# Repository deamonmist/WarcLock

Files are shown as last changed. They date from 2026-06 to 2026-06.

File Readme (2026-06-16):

# WarcLock

> **A wardriving pocket watch with style.**

**By Deamonmist**

A portable war-driver built from basic components that passes as a nifty home-made analog clock. It shows the real time on a round TFT face with a satellite-connection indicator, battery gauge, active-wardriving indicator, and random messages — all wrapped in a digital Art Deco style.

---
## Contents

- Mission Statement
- Overall Design
  - Form Factor
  - Components
- Assembly
  - Wiring Diagrams
    - ATGM336H — GPS Module
    - GC9A01 — Round TFT Display
    - V474 — SD Card Module
    - XIAO ESP32-C5 — MCU Pin Usage
    - On/Off Switch (Left Side)
    - Wardrive Slide Switch (Right Side)
    - Dim Tactile Button
    - LiPo Battery
    - Battery Voltage Sense Circuit
  - Circuit Assembly
- 3D Printing
- Final Assembly
- Flashing Your XIAO ESP32-C5

---
## Mission Statement

The goal of this project is simple: use basic components to make a portable war-driver that can pass as some kind of nifty home-made clock.

---
## Overall Design

### Form Factor
A small 3D-printed case containing a series of small modules and development boards that display the real time on an analog clock. The clock comes with a satellite-connection indicator, battery-life gauge, active-wardriving indicator, and random messages. The design is based on a digital Art Deco style.

### Components
- **GPS module** (ATGM336H) with ceramic antenna
- **1.28" round TFT screen** (GC9A01)
- **SD module**
- **XIAO ESP32-C5**
- **400mAh LiPo battery** (AKZYTUE 3.7V 522332)
- **Perforated board**
- Leads
- Two sliding switches
- One tactile switch

---

## Assembly

### Wiring Diagrams
Complete pin mapping for all components.

**Note:** The XIAO ESP32-C5 silkscreen D-numbers do **not** match the GPIO numbers. Always use the **GPIO** column when writing firmware.

#### ATGM336H — GPS Module
| GPS Pin | XIAO Pin | GPIO |
| --- | --- | --- |
| TX | D7 (RX) | GPIO12 |
| RX | D6 (TX) | GPIO11 |
| VCC | 3V3 | — |
| GND | GND | — |

#### GC9A01 — Round TFT Display
| TFT Pin | XIAO Pin | GPIO |
| --- | --- | --- |
| SCL / SCK | D8 | GPIO8 |
| SDA / MOSI | D10 | GPIO10 |
| CS | D2 | GPIO25 |
| DC | D3 | GPIO7 |
| RST | D1 | GPIO0 |
| VCC | 3V3 | — |
| GND | GND | — |

#### V474 — SD Card Module
| SD Pin | XIAO Pin | GPIO |
| --- | --- | --- |
| SCK | D8 (shared SPI) | GPIO8 |
| MOSI | D10 (shared SPI) | GPIO10 |
| MISO | D9 (shared SPI) | GPIO9 |
| CS | D0 | GPIO1 |
| VCC | 3V3 | — |
| GND | GND | — |

#### XIAO ESP32-C5 — MCU Pin Usage
| Function | XIAO Pin | GPIO |
| --- | --- | --- |
| SPI SCK | D8 | GPIO8 |
| SPI MOSI | D10 | GPIO10 |
| SPI MISO | D9 | GPIO9 |
| GPS RX (← GPS TX) | D7 | GPIO12 |
| GPS TX (→ GPS RX) | D6 | GPIO11 |
| TFT CS | D2 | GPIO25 |
| TFT DC | D3 | GPIO7 |
| TFT RST | D1 | GPIO0 |
| SD CS | D0 | GPIO1 |
| Wardrive Switch | D5 | GPIO24 |
| Dim Button | D4 | GPIO23 |
| Battery +/− | BAT pads | — |

#### On/Off Switch (Left Side)
| Switch Leg | XIAO Pin | GPIO |
| --- | --- | --- |
| Leg 1 (signal) | Bat + on XIAO| — |
| Leg 2 (common) | Bat + on Battery | — |
Interrupt the positive battery line with a switch.

#### Wardrive Slide Switch (Right Side)
| Switch Leg | XIAO Pin | GPIO |
| --- | --- | --- |
| Leg 1 (signal) | D5 | GPIO24 |
| Leg 2 (common) | GND | — |
`LOW` = wardrive active. `HIGH` = idle. Internal pullup enabled in firmware.

#### Dim Tactile Button
| Button Leg | XIAO Pin | GPIO |
| --- | --- | --- |
| Leg 1 (signal) | D4 | GPIO23 |
| Leg 2 (common) | GND | — |
Press toggles black-screen dim. Auto-dims after 2 minutes. Internal pullup enabled.

#### LiPo Battery
| Battery Wire | XIAO Pad | Note |
| --- | --- | --- |
| Positive (+) | BAT + | Soldered direct to pad |
| Negative (−) | BAT − | Soldered direct to pad |
Charged via USB-C. The onboard SGM40567 handles charge management. Do not exceed the 500mAh cell rating.

#### Battery Voltage Sense Circuit (onboard)
| Signal | XIAO Pin | GPIO | Note |
| --- | --- | --- | --- |
| ADC input | — | GPIO6 | Reads divided BAT voltage |
| ADC enable | Back pad A4 | GPIO26 | Drive HIGH to enable, LOW when idle |

---
### Circuit Assembly

Because a perforated board, modules, and dev boards are being packed into a very small space, there is a lot to fit. A general step-by-step visual guide is provided, but representing the wiring visually is too challenging — please refer to the [wiring diagrams](#wiring-diagrams) above.

Download READ-Me-WarcLock.docx for step by step instructions with pictures.

## 3D Printing
There are **5 parts** to print, listed on the GitHub page for download. From bottom to top:

- `ClockBottomInlay.stl`
- `ClockBottomSupports.stl`
- `ClockBodywSupports.stl`
- `ClockTopwSuppports.stl`
- `ClockDetailInlay.stl`

All prints include designed-in supports. If they're laid flat for printing, you should not need to add any slicer supports.

> 🛠️ You may occasionally get an error on `ClockBodywSupports.stl`. You can enable slicer supports, but they make it harder to remove the design supports. If this file starts to spaghettify, enable supports.

---
## Final Assembly

Refer to READ-Me-WarcLock.docx for step by step instructions with pictures.

The pieces used in final construction, from left to right:

- `ClockBottomInlay.stl`
- `ClockBottomwSupports.stl`
- WiFi antenna
- `ClockBodywSupports.stl`
- Soldered components
- `ClockTopwSupports.stl`
- `ClockDetailInlay.stl`

1. Apply super glue to the back of the bottom plate.
2. Attach the back plate to the bottom plate (and place an NFC tag if desired).
3. The antenna that comes with the XIAO ESP32-C5 must have its connection end fed through the hole in the clock body housing.
4. The connection end of the antenna fits easily.
5. Attach the antenna connection end to the XIAO ESP32-C5's U.FL port.
6. Carefully place the clock into the clock body housing. You'll have to bend the wings of the slide switches to fit the slots made for them.
7. Test your hardware to ensure none of the cabling was compromised during the fitting.
8. Place the ceramic antenna into the slot at the bottom of the clock body housing.
9. Attach the antenna to the back of the clock body housing.
10. Remove the two sticker backs from the antenna and stick it in place.
11. Attach the assembled backplate to the bottom of the clock body housing. This may be glued later.
12. Carefully glue the tactile push button into the slot at the front of the clock top housing. The slit allows the button's wires to be buried into the clock body housing.
13. Begin to fit the clock top housing onto the clock body housing.
14. Once everything is working and fits snugly, use a few small dabs of super glue to make the assembly more permanent.

---
## Flashing Your XIAO ESP32-C5
The firmware that drives the clock display and wardriving was written for this project. Consider flashing it onto your XIAO ESP32-C5 **before** you stuff everything into the 3D-printed parts.

Use the Arduino IDE to install the firmware. There are **10 files** in total — drop all 10 into a new folder and open `WarcLock.ino` to get started.

You will need the following libraries:

```cpp
#include <Arduino.h>
#include <Arduino_GFX_Library.h>
#include <math.h>
#include <HardwareSerial.h>
#include <WiFi.h>
#include <SPI.h>
#include <SD.h>
```

The rest of the dependencies are included in the project files.

> When in doubt, flash again!

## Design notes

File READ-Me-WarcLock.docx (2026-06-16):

WarcLock

By Deamonmist

A wardriving pocket watch with style.

Readme

June 15th, 2026 | Status: 1.0.0-beta.1

# Contents

Pg 1. – Contents

Pg 1. – Mission Statement

Pg 2. – Overall Design

– Form Factor

– Components

Pg 3. – Assembly

– Wiring Diagrams

Pg 5. – Circuit Assembly

Pg 9. – 3D Printing

Pg 10. – Final Assembly
Pg 18. – Flashing Your XIAO ESP32-C5

# Mission Statement

The goal of this project is simple: use basic components to make a portable war-driver that can pass as some kind of nifty home-made clock.

# Overall Design

## Form Factor

Small 3d-printed case containing a series of small modules and development boards that can display the real time on an analog clock. Clock comes with satellite connection indicator, battery life gauge, active wardriving indicator, and random messages. The design is based on a digital Arte Deco style.

## Components

- GPS module (ATGM336H) with ceramic antenna
- 1.28” TFT screen (GC9A01TFT)
- SD Module
- Xiao ESP32-C5
- 400mAh LiPo battery (AKZYTUE 3.7V 522332)
- Perforated Board
- Leads
- Two sliding switches
- 1 tactile switch

# Assembly

## Wiring Diagrams

Complete pin mapping for all components. XIAO ESP32-C5 silkscreen D-numbers do not match GPIO numbers — always use the GPIO column when writing firmware.

## ATGM336H — GPS Module

GPS Pin | XIAO Pin | GPIO
TX | D7 (RX) | GPIO12
RX | D6 (TX) | GPIO11
VCC | 3V3 | —
GND | GND | —

## GC9A01 — Round TFT Display

TFT Pin | XIAO Pin | GPIO
SCL / SCK | D8 | GPIO8
SDA / MOSI | D10 | GPIO10
CS | D2 | GPIO25
DC | D3 | GPIO7
RST | D1 | GPIO0
VCC | 3V3 | —
GND | GND | —

## V474 — SD Card Module

SD Pin | XIAO Pin | GPIO
SCK | D8 (shared SPI) | GPIO8
MOSI | D10 (shared SPI) | GPIO10
MISO | D9 (shared SPI) | GPIO9
CS | D0 | GPIO1
VCC | 3V3 | —
GND | GND | —

## XIAO ESP32-C5 — MCU Pin Usage

Function | XIAO Pin | GPIO
SPI SCK | D8 | GPIO8
SPI MOSI | D10 | GPIO10
SPI MISO | D9 | GPIO9
GPS RX (← GPS TX) | D7 | GPIO12
GPS TX (→ GPS RX) | D6 | GPIO11
TFT CS | D2 | GPIO25
TFT DC | D3 | GPIO7
TFT RST | D1 | GPIO0
SD CS | D0 | GPIO1
Wardrive Switch | D5 | GPIO24
Dim Button | D4 | GPIO23
Battery +/− | BAT pads | —

## On Off Switch (Left Side)

Switch Leg | XIAO Pin | GPIO
Leg 1 (signal) | Bat +
Leg 2 (common) | Bat + | —

Interrupt the positive battery line with a switch.

## Wardrive Slide Switch (Right Side)

Switch Leg | XIAO Pin | GPIO
Leg 1 (signal) | D5 | GPIO24
Leg 2 (common) | GND | —

LOW = wardrive active. HIGH = idle. Internal pullup enabled in firmware.

## Dim Tactile Button

Button Leg | XIAO Pin | GPIO
Leg 1 (signal) | D4 | GPIO23
Leg 2 (common) | GND | —

Press toggles black-screen dim. Auto-dims after 2 minutes. Internal pullup enabled.

## LiPo Battery (500mAh)

Battery Wire | XIAO Pad | Note
Positive (+) | BAT + | Soldered direct to pad
Negative (−) | BAT − | Soldered direct to pad

Charged via USB-C. SGM40567 onboard handles charge management. Do not exceed 500mAh cell rating.

## Battery Voltage Sense Circuit (onboard)

Signal | XIAO Pin | GPIO | Note
ADC input | — | GPIO6 | Reads divided BAT voltage
ADC enable | Back pad A4 | GPIO26 | Drive HIGH to enable, LOW when idle

# Circuit Assembly

Because a perforated board, modules, and dev boards are being used there is a lot to pack in a very small space. I have provided a general step by step visual guide. However, visually representing wiring is too challenging. Please refer to the wiring diagrams above.

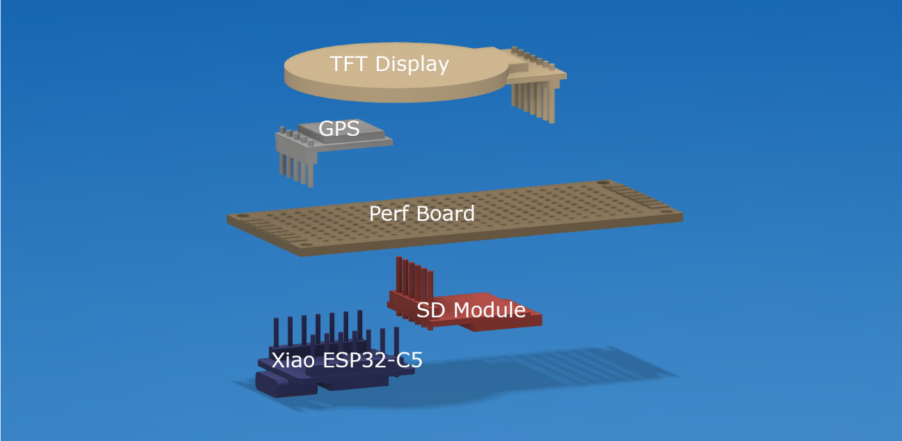
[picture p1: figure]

This is the rough orientation of the various components.

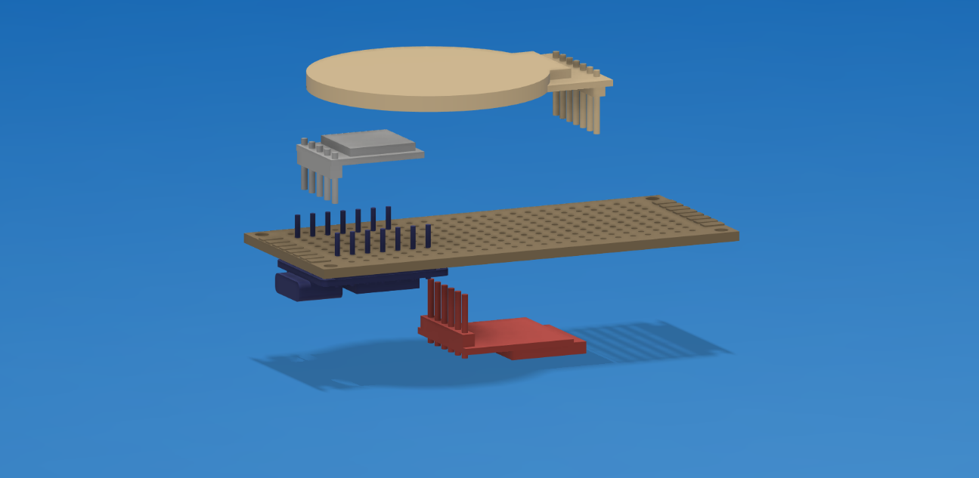
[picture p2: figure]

Start by moving the Xiao ESP32-C5 into the location shown. Solder one or two of the posts to the breadboard to keep it in place. Alternatively you can bend a pin or two flush with perf-board to hold it in place.

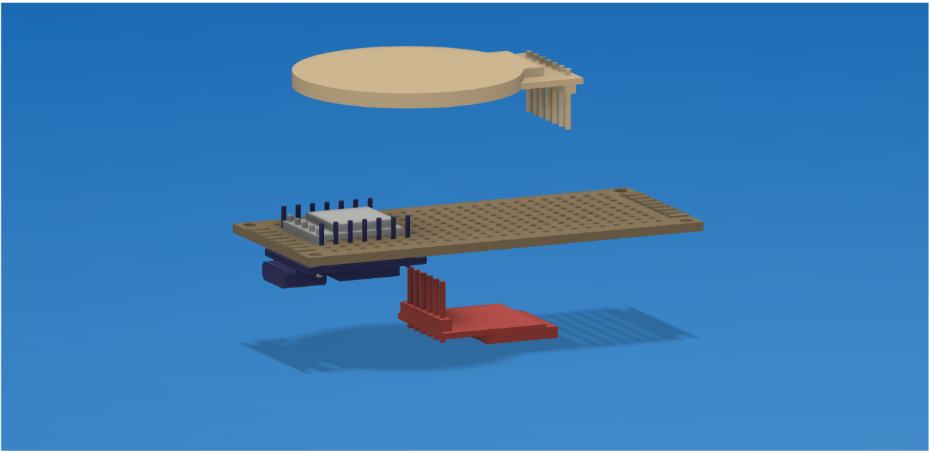
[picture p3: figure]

Next, move the GPS down. You may have to trim the pins to get it to fit. Again, solder in one or two places to keep it from moving.

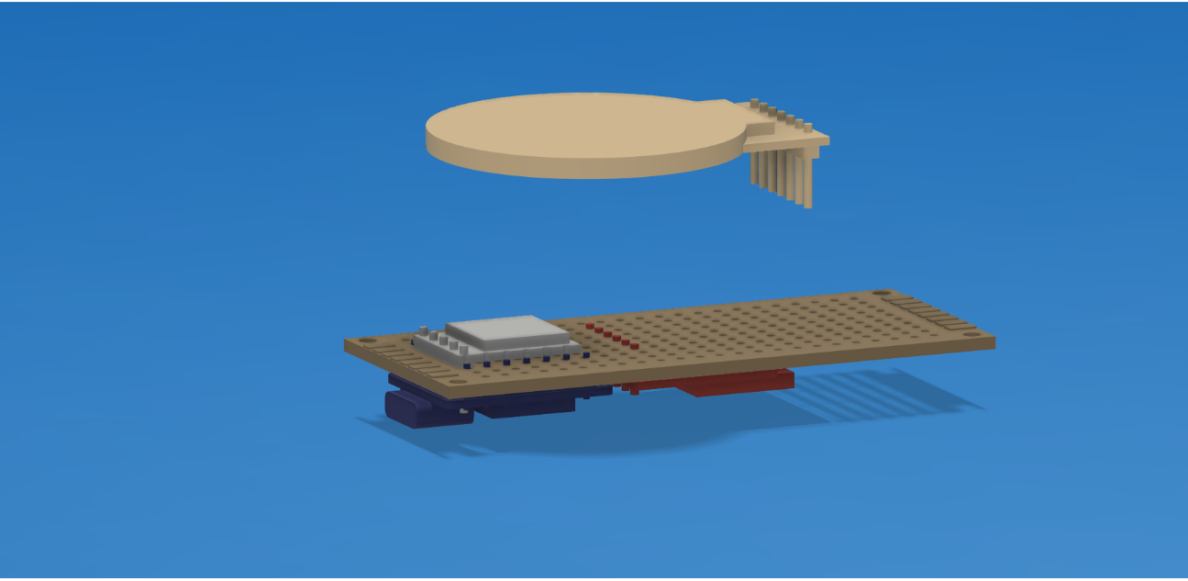
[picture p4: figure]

Now move the SD card up as shown. Solder into place.

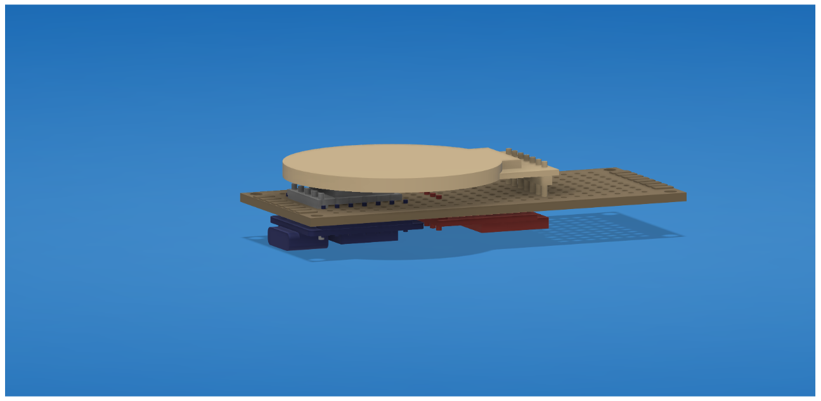
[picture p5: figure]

Now drop the screen down in place. You’ll want to leave enough of a gap between the perf-board and the TFT screen to hold the battery, or else the device will have to be much thicker to accommodate a battery.

See wiring charts below to solder the necessary leads into place.

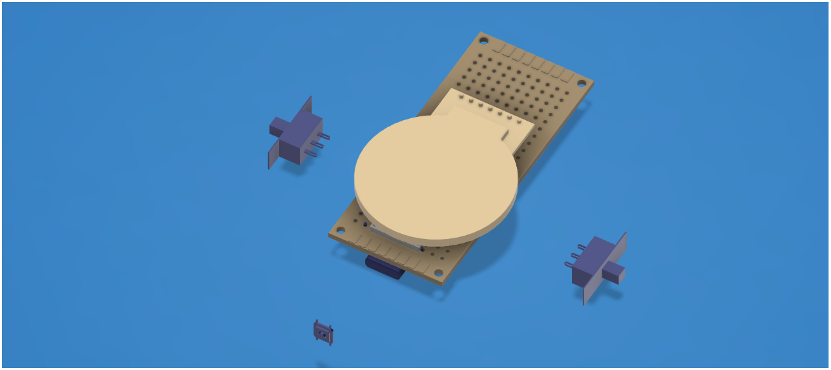
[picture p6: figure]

You’ll need two sliding switches and one tactile switch in this general orientation. You’ll want to use short leads on the sliding switches so they can fit properly into the housing.

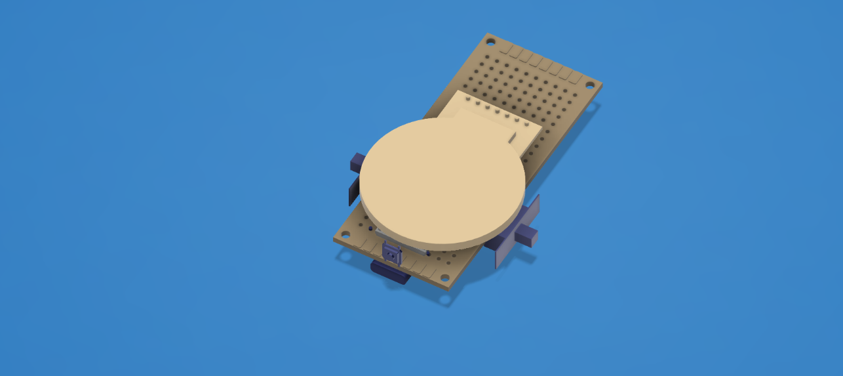
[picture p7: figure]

This will be the final orientation of the switches and buttons for the housing.

Once your wiring is all set, it’s time to carefully trim the excess perf board away. You’ll want to make sure the front of the perf board follows the curves of the screen. The back can be largely chopped away entirely.

## 3D Printing

There are a total of 5 parts that need to be printed. They are listed on the github page for download. They include from bottom to top:

1. ClockBottomInlay.stl
2. ClockBottomSupports.stl
3. ClockBodywSupports.stl
4. ClockTopwSuppports.stl
5. ClockDetailInlay.stl

All prints contain designed supports. If they are laid flat for print, you should not need to add any supports.

Sometimes you’ll get an error on the ClockBodywSupports.stl file, so you can enable them but they just make it harder to take the design supports out. If this file starts to spagettify, enable supports.

## Final Assembly

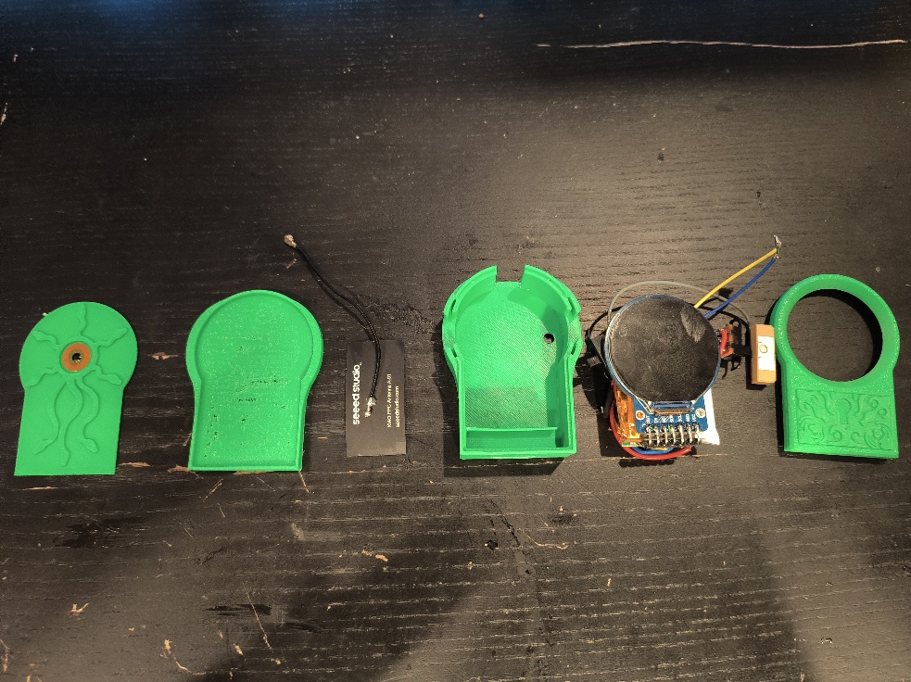
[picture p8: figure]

1. These are the pieces that will be used in the final construction from left to right:

- ClockBottomInlay.stl
- ClockBottomwSupports.stl
- WiFi Antenna
- ClockBodywSupports.stl
- Soldered Components
- ClockTopwSupports.stl
- ClockDetailInlay.stl

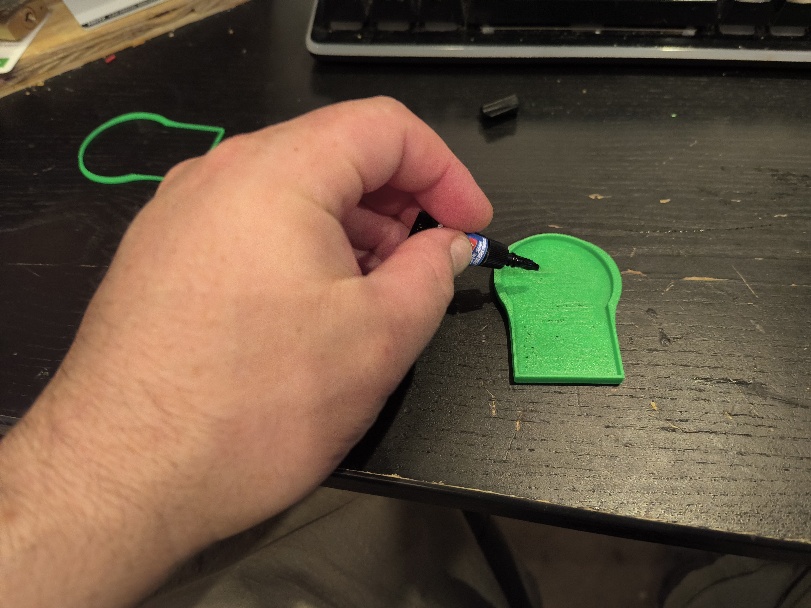
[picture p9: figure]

2. Apply crazy glue to the back of the bottom plate.

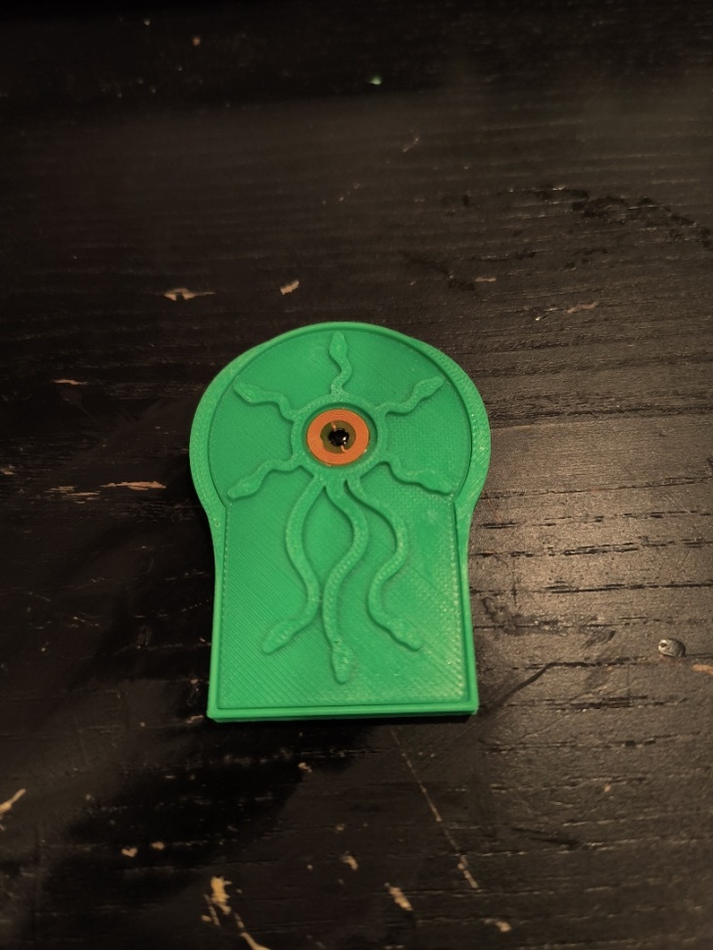
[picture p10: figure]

3. Attach the back plate to the bottom plate (and place NFC tag if desired).

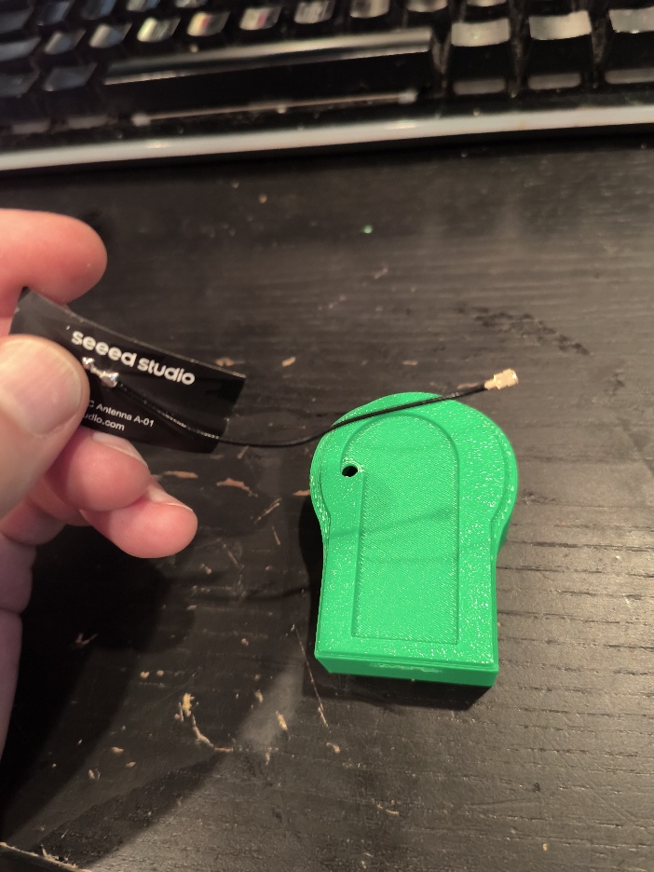
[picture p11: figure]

4. The antenna that comes with the Xiao ESP32-C5 must have the connection end fed through the hole in the clock body housing.

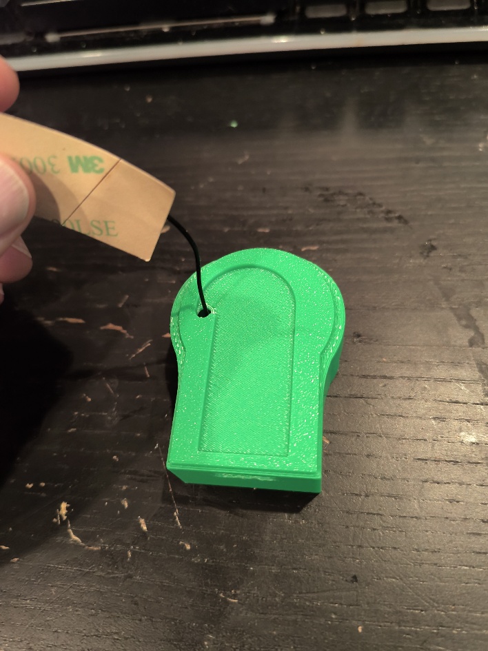
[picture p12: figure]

5. The connection end of the antenna fits easily.

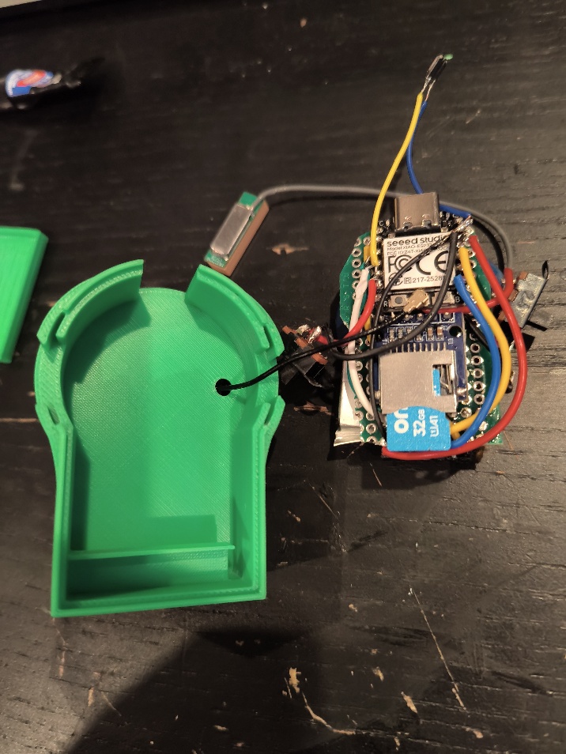
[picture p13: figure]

6. Attach the antenna connection end to the Xiao ESP32-C5’s UFI port.

7. Carefully place the clock into the clock body housing. You’ll have to bend the wings of the slide switches to fit the slots made for the wings.

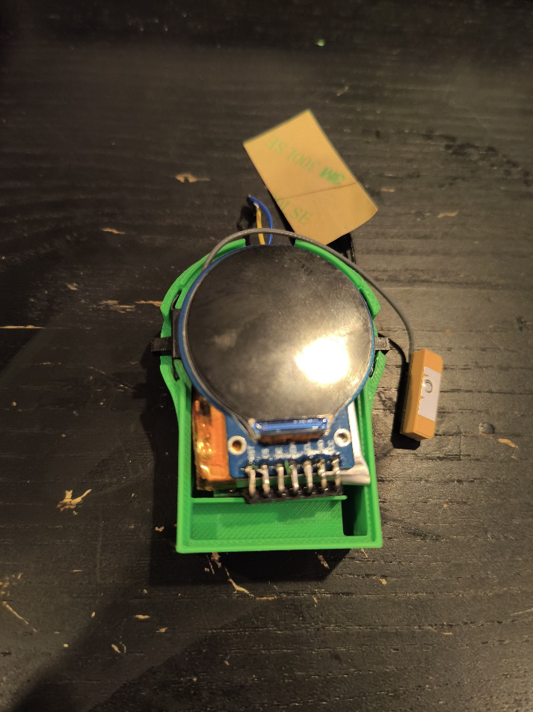
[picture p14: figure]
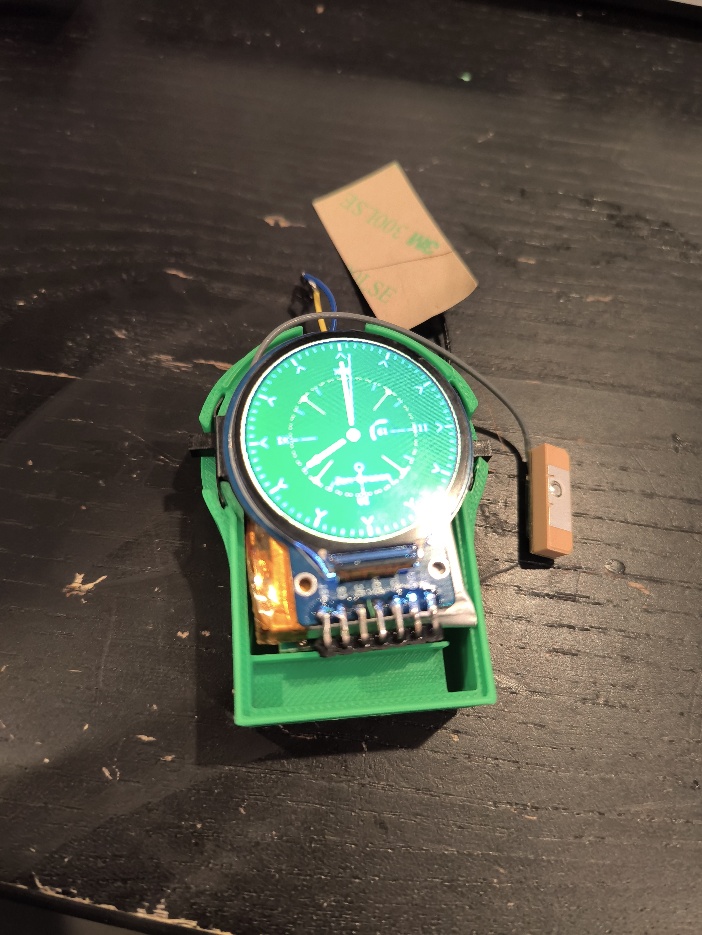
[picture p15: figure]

8. Test your hardware to ensure none of the cabling was compromised during the fitting.

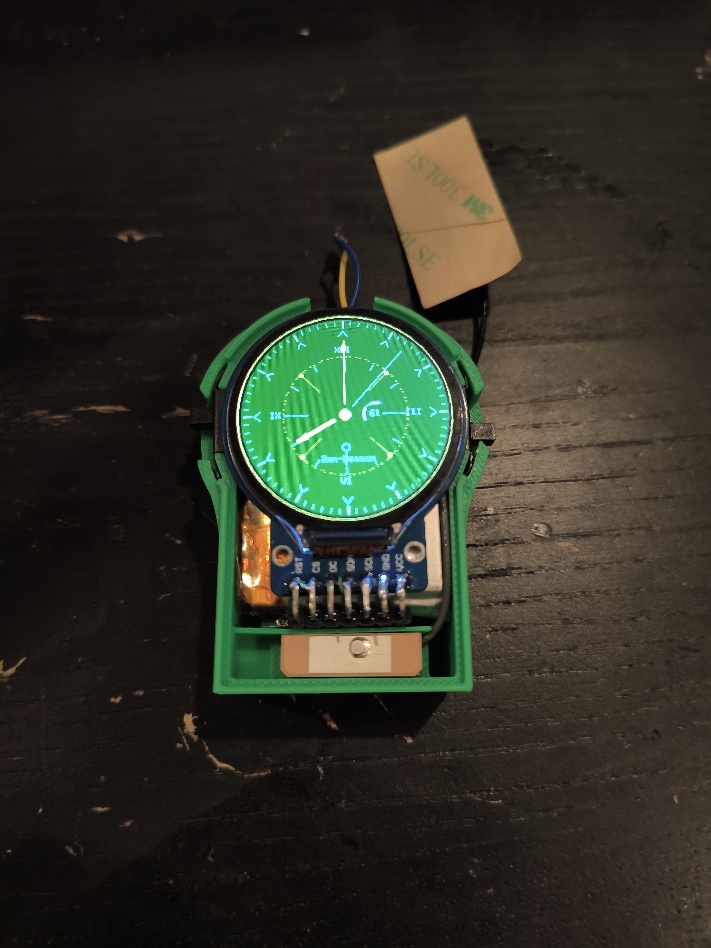
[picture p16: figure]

9. Place the ceramic antenna into the slot at the bottom of the clock body housing.

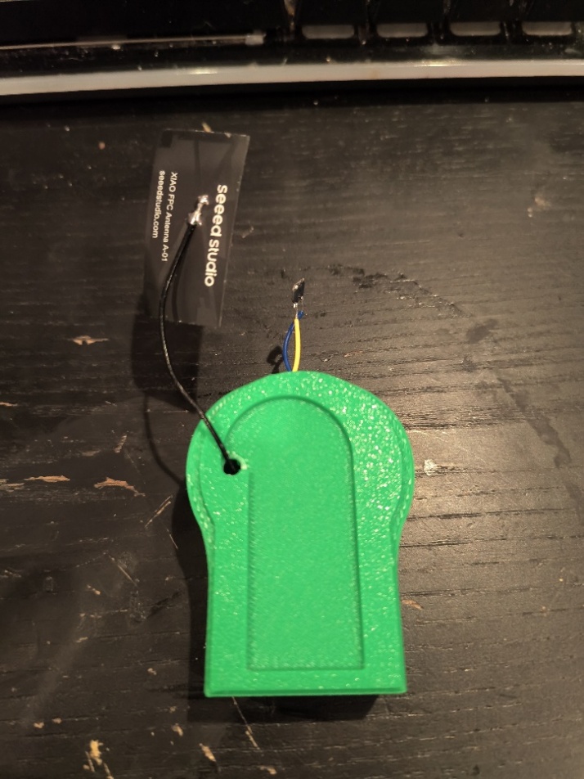
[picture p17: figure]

10. It is time to attach the antenna to the back of the clock body housing.

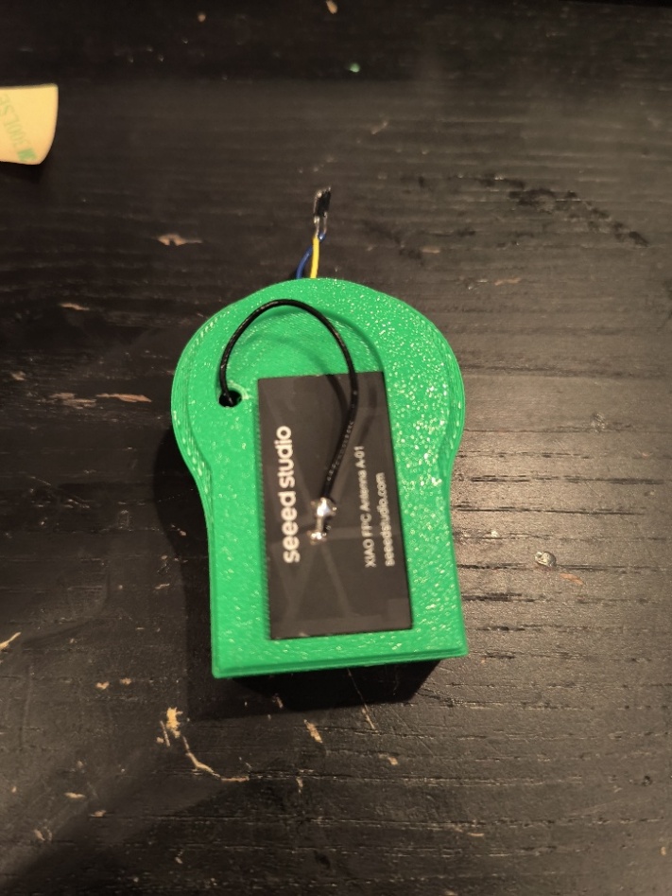
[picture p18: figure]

11. Remove the two sticker backs from the antenna and stick it in place.

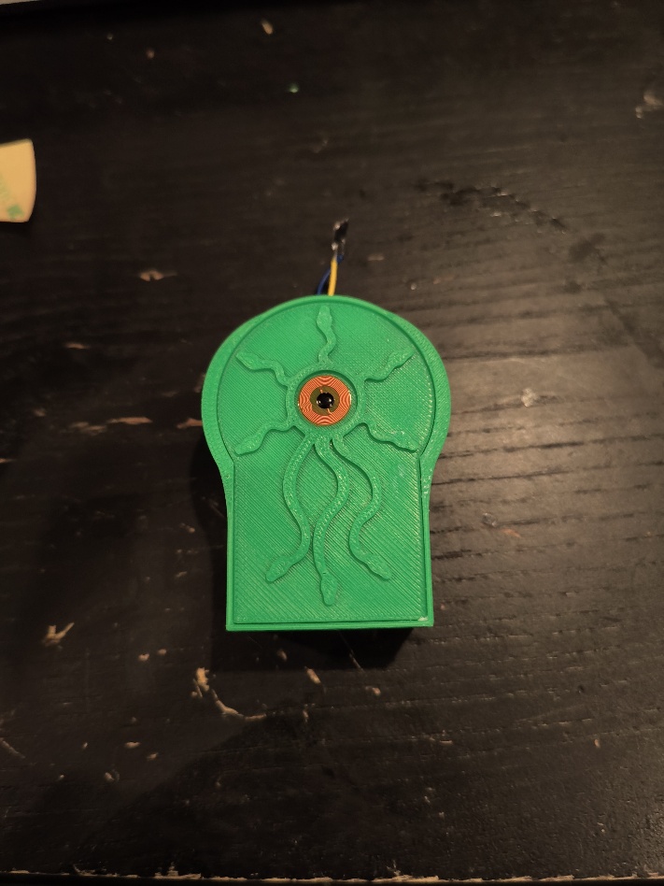
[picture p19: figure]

12. Attach the assembled backplate to the bottom of the clock body housing. This may be glued later.

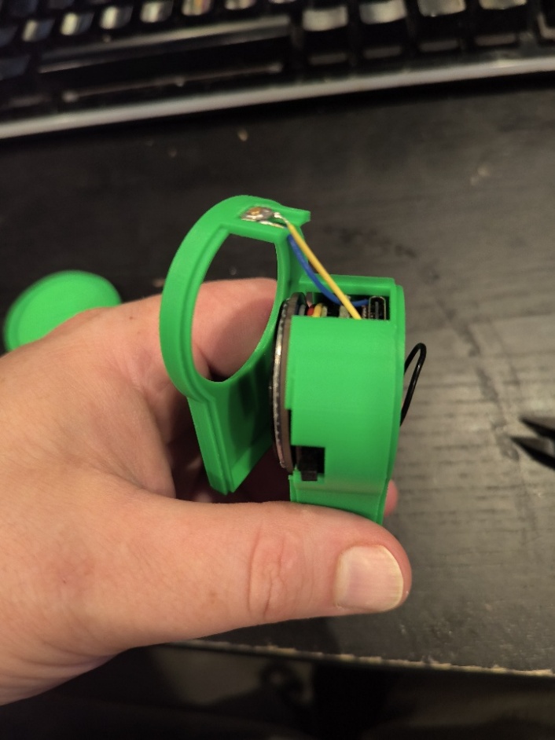
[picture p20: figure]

13. Carefully glue the tactile push button into the slot at the front of the clock top housing. The slit will allow the cables to the wire to be buried into the clock body housing.

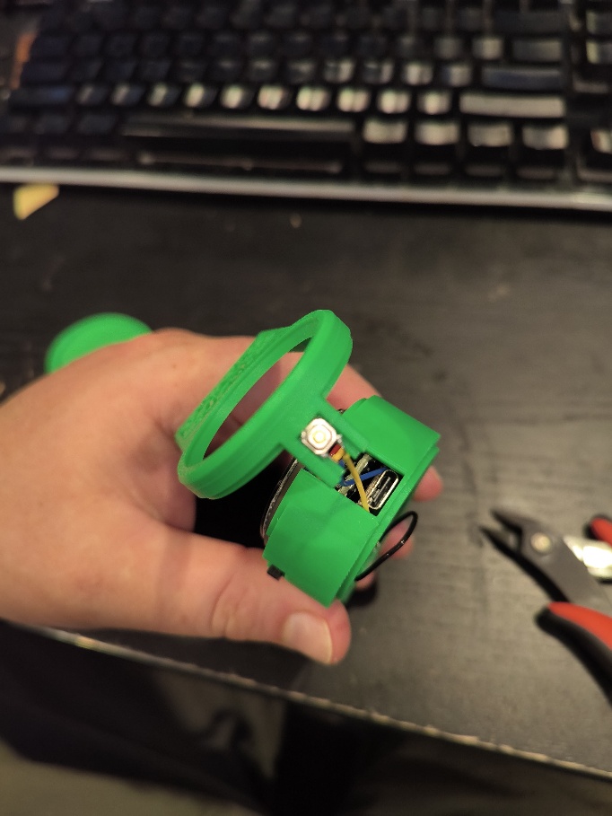
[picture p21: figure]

14. Begin to fit the clock top housing onto the clock body housing.

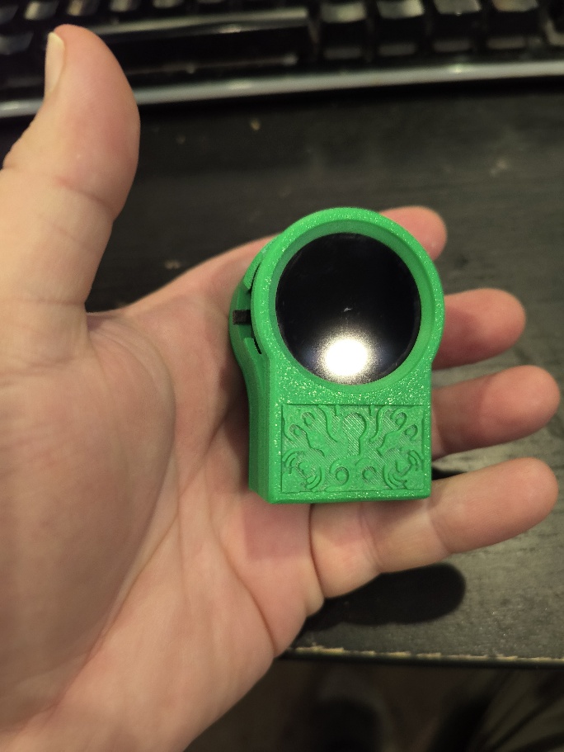
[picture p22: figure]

15. Once everything is working and fits snugly, use a few small dabs of super glue to make the assembly more permanent.

## Flashing Your XIAO ESP32-C5

The firmware that allows the watch to display the time and wardrive was made by me. You might consider flashing the firmware onto your XIAO ESP32-C5 before you stuff everything into the 3d printed parts.

Use Arduino SDK to install the firmware on your device. There are 10 files in total. Just drag all 10 to a new folder and open the “WarcLock.ino” file with Arduino SDK to get started.

You will need the following libraries:

Arduino.h

Arduino_GFX_Library.h

<math.h>

<HardwareSerial.h>

<WiFi.h>

<SPI.h>

<SD.h>

The rest of the libraries are included in the files.

When in doubt, flash again!

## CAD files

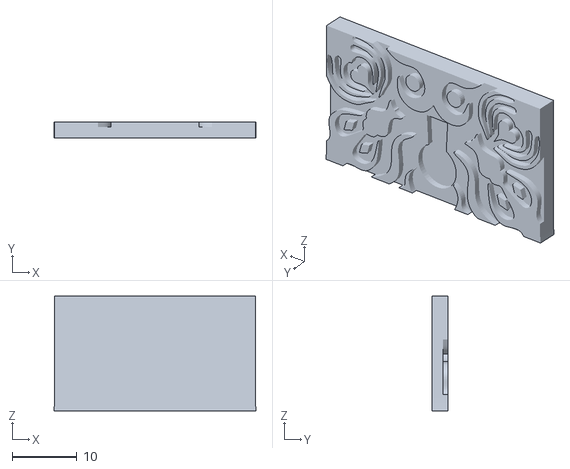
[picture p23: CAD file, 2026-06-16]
3DPrintFiles/ClockDetailInlay.stl
31.2 x 2.50 x 17.7

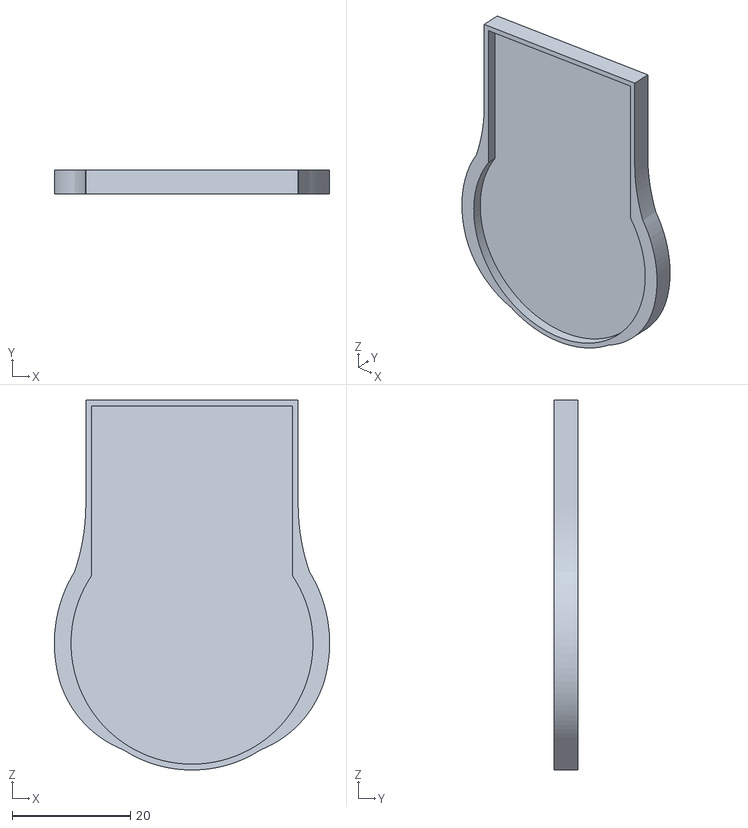
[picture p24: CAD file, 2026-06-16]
3DPrintFiles/ClockBottomwSupports.stl
46.6 x 4.00 x 62.7

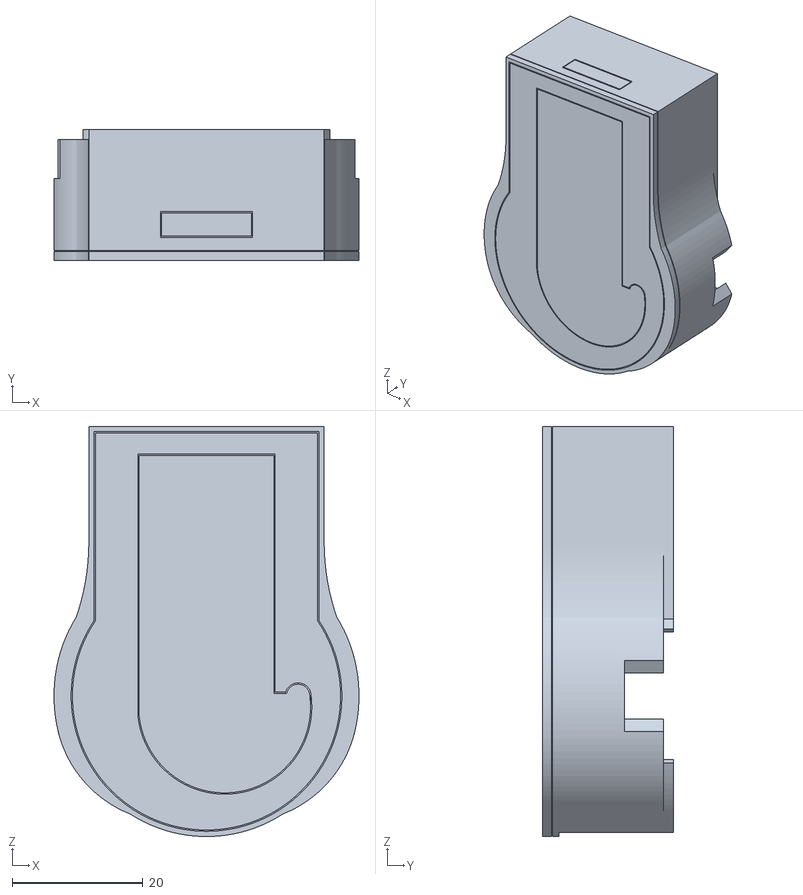
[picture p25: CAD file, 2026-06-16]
3DPrintFiles/ClockBodywSupports.stl
46.6 x 20.0 x 62.7

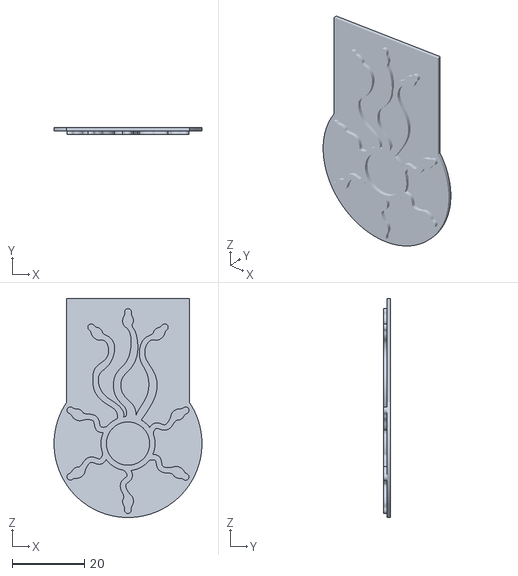
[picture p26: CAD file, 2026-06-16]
3DPrintFiles/ClockBottomInlay.stl
41.0 x 2.00 x 60.7

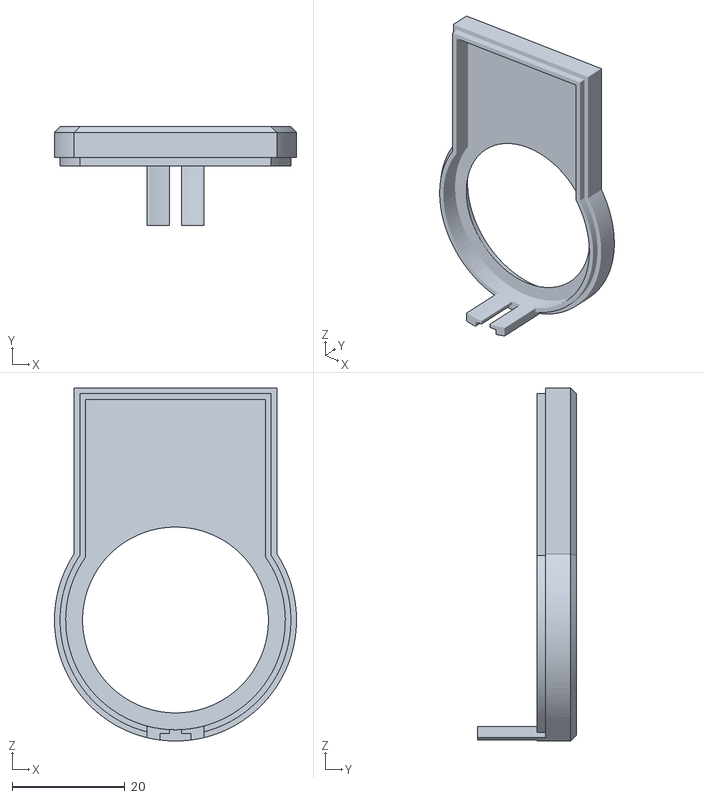
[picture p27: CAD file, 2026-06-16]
3DPrintFiles/ClockTopwSupports.stl
43.0 x 17.5 x 62.7

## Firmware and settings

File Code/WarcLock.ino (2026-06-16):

/*
 * WarcLock.ino — by Deamonmist (multi-file)
 * XIAO ESP32-C5 + GC9A01 round TFT + ATGM336H GPS + V474 microSD
 *
 * Files:
 *   WarcLock.ino  — globals, setup(), loop(), battery, mode controller
 *   config.h        — pins, palette, geometry, shared globals
 *   display.h/.cpp  — canvas framebuffer + full-frame rendering
 *   gpsclock.h/.cpp — GPS parsing + drift-free timekeeping
 *   wardrive.h/.cpp — async WiFi scan + WiGLE CSV logging
 *   messages.h/.cpp — scrolling message phrases
 *
 * Tools -> PSRAM must be ENABLED (canvas framebuffer lives in PSRAM).
 *
 * Slide switch on D5/GPIO24:
 *   LOW  -> WARDRIVE: scan + log to timestamped CSV
 *   HIGH -> IDLE: radio off, clock + display only
 *
 * Dim button on D4/GPIO23: press to toggle black screen, auto-dims after
 * DIM_TIMEOUT ms of inactivity.
 */

#include "config.h"
#include "display.h"
#include "gpsclock.h"
#include "wardrive.h"

// ── Global storage (declared extern in config.h) ──────────────────────
Arduino_GFX  *gfx          = nullptr;
volatile bool g_gpsLocked  = false;
volatile bool g_wardriveOn = false;
float g_lat = 0.0f, g_lon = 0.0f, g_alt = 0.0f, g_hdop = 99.9f;
bool  g_sdOK = false;
char  g_logFile[32] = "";
int   g_batPct = 0;
bool  g_charging = false;
bool  g_dimmed   = false;

// ── Battery ───────────────────────────────────────────────────────────
static int batteryPercent(float v) {
  struct { float v; int p; } curve[] = {
    {4.20f,100}, {4.10f,90}, {4.00f,80}, {3.90f,65}, {3.80f,50},
    {3.70f,35},  {3.60f,20}, {3.50f,12}, {3.40f,6},  {3.30f,3}, {3.00f,0}
  };
  const int n = sizeof(curve) / sizeof(curve[0]);
  if (v >= curve[0].v)   return 100;
  if (v <= curve[n-1].v) return 0;
  for (int i = 0; i < n - 1; i++) {
    if (v <= curve[i].v && v > curve[i+1].v) {
      float frac = (v - curve[i+1].v) / (curve[i].v - curve[i+1].v);
      return (int)(curve[i+1].p + frac * (curve[i].p - curve[i+1].p) + 0.5f);
    }
  }
  return 0;
}

static void updateBattery() {
  digitalWrite(BAT_VOLT_PIN_EN, HIGH);
  delay(5);
  long raw = 0;
  for (int i = 0; i < 16; i++) { raw += analogRead(BAT_VOLT_PIN); delay(2); }
  raw /= 16;
  digitalWrite(BAT_VOLT_PIN_EN, LOW);
  float voltage = raw * (3.3f / 4095.0f) * 2.0f * BAT_CALIBRATION;
  g_charging = (voltage > CHARGE_THRESHOLD);
  g_batPct   = batteryPercent(voltage);
  Serial.printf("Battery: %.2fV  (%d%%)  %s\n",
                voltage, g_batPct, g_charging ? "CHARGING" : "on battery");
}

// ── Setup ─────────────────────────────────────────────────────────────
void setup() {
  setCpuFrequencyMhz(80);
  Serial.begin(115200);
  delay(500);
  Serial.println("\n== ZenDeamon WarWatch ==");
  Serial.printf("CPU @ %d MHz\n", getCpuFrequencyMhz());

  if (!displayBegin()) {
    Serial.println("ERROR: canvas/display init failed.");
    Serial.println("Check that Tools -> PSRAM is ENABLED.");
    while (1) delay(100);
  }
  Serial.println("Display OK");

  analogReadResolution(12);
  analogSetAttenuation(ADC_11db);
  pinMode(BAT_VOLT_PIN_EN, OUTPUT);
  digitalWrite(BAT_VOLT_PIN_EN, LOW);
  updateBattery();

  renderFrame();

  g_sdOK = wardriveInitSD();
  gpsBegin();

  pinMode(WARDRIVE_SW, INPUT_PULLUP);
  pinMode(DIM_BTN,     INPUT_PULLUP);

  Serial.println("Setup complete");
}

// ── Loop ──────────────────────────────────────────────────────────────
void loop() {
  gpsFeed();
  gpsUpdate();

  // Wardrive switch
  bool sw = (digitalRead(WARDRIVE_SW) == LOW);
  static bool prevSw   = false;
  static bool firstRun = true;
  if (firstRun) { prevSw = !sw; firstRun = false; }

  if (sw != prevSw) {
    if (sw)  wardriveEnter();
    else     wardriveExit();
    prevSw = sw;
  }
  g_wardriveOn = sw;

  if (sw) wardriveTask();

  // Battery every 10 s
  static unsigned long lastBat = 0;
  if (millis() - lastBat > 10000UL) {
    lastBat = millis();
    updateBattery();
  }

  // Dim button + auto-dim
  static unsigned long lastActivity = millis();
  static bool          prevBtn      = HIGH;
  bool curBtn = digitalRead(DIM_BTN);
  if (prevBtn == HIGH && curBtn == LOW) {
    g_dimmed     = !g_dimmed;
    lastActivity = millis();
  }
  prevBtn = curBtn;
  if (g_gpsLocked || g_wardriveOn) lastActivity = millis();
  if (!g_dimmed && (millis() - lastActivity > DIM_TIMEOUT)) {
    g_dimmed = true;
  }

  // Redraw on state change
  static int  lastSec      = -1;
  static bool lastLocked   = false;
  static bool lastWardrive = false;
  static bool lastCharging = false;
  static bool lastDimmed   = false;
  int h, m, s, h24;
  getClock(h, m, s, h24);
  if (s != lastSec || g_gpsLocked != lastLocked ||
      g_wardriveOn != lastWardrive || g_charging != lastCharging ||
      g_dimmed != lastDimmed) {
    lastSec      = s;
    lastLocked   = g_gpsLocked;
    lastWardrive = g_wardriveOn;
    lastCharging = g_charging;
    lastDimmed   = g_dimmed;
    renderFrame();
  }
}

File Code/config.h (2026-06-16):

/*
 * config.h — shared constants and global declarations
 * WarcLock.ino — by Deamonmist (multi-file)
 */
#pragma once
#include <Arduino.h>
#include <Arduino_GFX_Library.h>

// ── Timezone ──────────────────────────────────────────────────────────
#define UTC_OFFSET  -4    // EDT = -4, EST = -5

// ── Display pins ──────────────────────────────────────────────────────
#define TFT_CS   25
#define TFT_DC    7
#define TFT_RST   0
#define TFT_SCK   8
#define TFT_MOSI 10

// ── SD card ───────────────────────────────────────────────────────────
#define SD_CS     1

// ── GPS UART ──────────────────────────────────────────────────────────
#define GPS_RX   12
#define GPS_TX   11

// ── Wardrive slide switch ─────────────────────────────────────────────
#define WARDRIVE_SW  24   // D5 = GPIO24 on XIAO ESP32-C5. Switch to GND. LOW=wardrive, HIGH=idle
#define DIM_BTN      23   // D4 = GPIO23. Tactile button to GND (INPUT_PULLUP)
#define DIM_TIMEOUT  120000UL  // auto-dim after 2 minutes of inactivity (ms)

// ── Battery voltage sensing ───────────────────────────────────────────
#define BAT_VOLT_PIN     6
#define BAT_VOLT_PIN_EN  26
#define BAT_CALIBRATION  1.16f
#define CHARGE_THRESHOLD 4.22f

// ── Palette (RGB565) ──────────────────────────────────────────────────
#define C_BLACK   0x0000
#define C_DKGREEN 0x0A21
#define C_GOLD    0xC488
#define C_GOLD2   0xE74C
#define C_TEAL    0x15F6
#define C_TEAL2   0x2EFA
#define C_TEAL3   0x0A4A
#define C_CREAM   0xD651
#define C_BLUE    0x2D7F
#define C_BLUE2   0x5CDF
#define C_AMBER   0xDD28
#define C_RED     0xD14A
#define C_GREEN   0x2E68   // reserved
#define C_TRACK   0x09C5

// ── Face geometry ─────────────────────────────────────────────────────
#define CX  120
#define CY  120
#define R   115
#define WIFI_X  CX
#define WIFI_Y  78
#define BAT_GX  (CX + 34)
#define BAT_GY  CY
#define BAT_GR  14

// ── Shared globals (defined in WarWatch01.ino) ────────────────────────
extern Arduino_GFX *gfx;

extern volatile bool g_gpsLocked;
extern volatile bool g_wardriveOn;
extern float g_lat, g_lon, g_alt, g_hdop;

extern bool g_sdOK;
extern char g_logFile[32];

extern int  g_batPct;
extern bool g_charging;
extern bool g_dimmed;          // true when display is in black-screen dim mode

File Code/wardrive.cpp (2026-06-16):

/* WarcLock.ino — by Deamonmist (multi-file)
 * wardrive.cpp — WiFi scanning + WiGLE CSV logging implementation
 */
#include "config.h"
#include "wardrive.h"
#include "gpsclock.h"
#include <WiFi.h>
#include <SPI.h>
#include <SD.h>

#define SCAN_INTERVAL_MS  30000UL
#define TMP_FILE          "/session_tmp.csv"

static bool          scanning    = false;
static unsigned long lastScan    = 0;
static char          g_startName[32] = "";   // start timestamp for filename

bool wardriveInitSD() {
  pinMode(TFT_CS, OUTPUT);
  digitalWrite(TFT_CS, HIGH);
  delay(10);
  if (!SD.begin(SD_CS)) {
    Serial.println("SD init failed — check wiring / FAT32 format");
    return false;
  }
  Serial.println("SD card OK");
  return true;
}

// Format a 12-hour time string like "0223PM" from 24h hour + minute + second
static void fmt12(char *buf, int h24, int m) {
  const char *ampm = (h24 >= 12) ? "PM" : "AM";
  int h12 = h24 % 12;
  if (h12 == 0) h12 = 12;
  snprintf(buf, 8, "%02d%02dM", h12, m);  // placeholder, overwrite below
  snprintf(buf, 8, "%02d%02d%s", h12, m, ampm);
}

// Build a full filename: /MM-DD-YYYY-HHMMam-HHMMpm.csv
// Pass the start stamp string and current time for the end stamp.
static void buildFilename(char *out, size_t sz,
                          const char *startStamp,
                          int h24, int m,
                          int day, int mon, int yr) {
  char endStamp[8];
  fmt12(endStamp, h24, m);
  snprintf(out, sz, "/%02d-%02d-%04d-%s-%s.csv", mon, day, yr, startStamp, endStamp);
}

static void openSessionFile() {
  if (!g_sdOK) return;

  // Capture start time
  int h, m, s, h24;
  getClock(h, m, s, h24);

  // Date from GPS if valid, otherwise sensible default
  int day = gps.date.isValid() ? gps.date.day()   : 1;
  int mon = gps.date.isValid() ? gps.date.month() : 1;
  int yr  = gps.date.isValid() ? gps.date.year()  : 2026;

  fmt12(g_startName, h24, m);

  // If a temp file exists from a previous crash, append to it —
  // the data is still valid. Only write the header for a fresh file.
  bool isNew = !SD.exists(TMP_FILE);
  File f = SD.open(TMP_FILE, FILE_APPEND);
  if (!f) { Serial.println("Could not create session file"); return; }
  if (isNew) {
    f.println("WigleWifi-1.6,appRelease=WarWatch01,model=XIAO-ESP32C5,device=WarWatch,display=GC9A01,board=ESP32C5,brand=Seeed");
    f.println("MAC,SSID,AuthMode,FirstSeen,Channel,Frequency,RSSI,CurrentLatitude,CurrentLongitude,AltitudeMeters,AccuracyMeters,RCOIs,MfgrId,Type");
  }
  f.close();

  // Keep g_logFile pointing at the temp path for logResults to append to
  strncpy(g_logFile, TMP_FILE, sizeof(g_logFile));

  Serial.printf("Wardrive session started: %s at %s\n",
                (yr > 2000 ? "dated" : "undated"), g_startName);
}

static void closeSessionFile() {
  if (!g_sdOK || !SD.exists(TMP_FILE)) return;

  // Build the final filename using the end time
  int h, m, s, h24;
  getClock(h, m, s, h24);
  int day = gps.date.isValid() ? gps.date.day()   : 1;
  int mon = gps.date.isValid() ? gps.date.month() : 1;
  int yr  = gps.date.isValid() ? gps.date.year()  : 2026;

  char finalName[48];
  buildFilename(finalName, sizeof(finalName), g_startName, h24, m, day, mon, yr);

  // If a file with this exact name already exists (same-minute start+end),
  // append a short counter to avoid collision
  if (SD.exists(finalName)) {
    char tmp[52];
    snprintf(tmp, sizeof(tmp), "%.*s_2.csv", (int)strlen(finalName)-4, finalName);
    strncpy(finalName, tmp, sizeof(finalName));
  }

  // Copy temp -> final (SD lib has no rename)
  File src = SD.open(TMP_FILE, FILE_READ);
  File dst = SD.open(finalName, FILE_WRITE);
  if (!src || !dst) {
    Serial.println("Session rename failed — temp file kept");
    if (src) src.close();
    if (dst) dst.close();
    return;
  }

  uint8_t buf[512];
  while (src.available()) {
    int n = src.read(buf, sizeof(buf));
    dst.write(buf, n);
  }
  src.close();
  dst.close();
  SD.remove(TMP_FILE);

  strncpy(g_logFile, finalName, sizeof(g_logFile));
  Serial.printf("Session saved as: %s\n", finalName);
}

void wardriveEnter() {
  WiFi.mode(WIFI_STA);
  WiFi.disconnect();
  scanning = false;
  lastScan = 0;
  openSessionFile();
  Serial.println("Wardrive mode");
}

void wardriveExit() {
  if (scanning) { WiFi.scanDelete(); scanning = false; }
  closeSessionFile();
  WiFi.disconnect(true);
  WiFi.mode(WIFI_OFF);
  Serial.println("Wardrive session ended");
}

static String authCaps(wifi_auth_mode_t a) {
  switch (a) {
    case WIFI_AUTH_OPEN:           return "[ESS]";
    case WIFI_AUTH_WEP:            return "[WEP][ESS]";
    case WIFI_AUTH_WPA_PSK:        return "[WPA-PSK-CCMP][ESS]";
    case WIFI_AUTH_WPA2_PSK:       return "[WPA2-PSK-CCMP][ESS]";
    case WIFI_AUTH_WPA_WPA2_PSK:   return "[WPA-PSK-CCMP+TKIP][WPA2-PSK-CCMP+TKIP][ESS]";
    case WIFI_AUTH_WPA3_PSK:       return "[WPA3-SAE-CCMP][ESS]";
    case WIFI_AUTH_WPA2_WPA3_PSK:  return "[WPA2-PSK-CCMP][WPA3-SAE-CCMP][ESS]";
    default:                       return "[ESS]";
  }
}

static int channelToFreq(int ch) {
  if (ch >= 1 && ch <= 13)    return 2407 + ch * 5;
  if (ch == 14)               return 2484;
  if (ch >= 36 && ch <= 177)  return 5000 + ch * 5;
  return 0;
}

static void logResults(int n) {
  if (n <= 0) return;
  int h, m, s, h24;
  getClock(h, m, s, h24);
  char ts[24];
  snprintf(ts, sizeof(ts), "%04d-%02d-%02d %02d:%02d:%02d",
    gps.date.isValid() ? gps.date.year()  : 2026,
    gps.date.isValid() ? gps.date.month() : 1,
    gps.date.isValid() ? gps.date.day()   : 1,
    h24, m, s);

  File f = SD.open(g_logFile, FILE_APPEND);
  if (!f) { Serial.println("SD append failed"); return; }
  for (int i = 0; i < n; i++) {
    String bssid = WiFi.BSSIDstr(i);
    String ssid  = WiFi.SSID(i);
    ssid.replace(",", " ");
    String caps  = authCaps(WiFi.encryptionType(i));
    int ch   = WiFi.channel(i);
    int freq = channelToFreq(ch);
    int rssi = WiFi.RSSI(i);
    char line[220];
    snprintf(line, sizeof(line),
      "%s,%s,%s,%s,%d,%d,%d,%.6f,%.6f,%.1f,%.1f,,,WIFI",
      bssid.c_str(), ssid.c_str(), caps.c_str(), ts,
      ch, freq, rssi, g_lat, g_lon, g_alt, g_hdop * 5.0f);
    f.println(line);
  }
  f.close();
  Serial.printf("Logged %d networks\n", n);
}

void wardriveTask() {
  if (!g_gpsLocked || !g_sdOK) return;

  if (!scanning) {
    if (millis() - lastScan > SCAN_INTERVAL_MS) {
      WiFi.scanNetworks(true, true);
      scanning = true;
    }
  } else {
    int n = WiFi.scanComplete();
    if (n >= 0) {
      logResults(n);
      WiFi.scanDelete();
      scanning = false;
      lastScan = millis();
    } else if (n == WIFI_SCAN_FAILED) {
      WiFi.scanDelete();
      scanning = false;
      lastScan = millis();
    }
  }
}
